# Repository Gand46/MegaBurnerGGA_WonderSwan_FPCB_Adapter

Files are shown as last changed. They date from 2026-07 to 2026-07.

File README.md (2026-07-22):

# WonderSwan SOP-44 to TSOP II-44 FPCB adapter

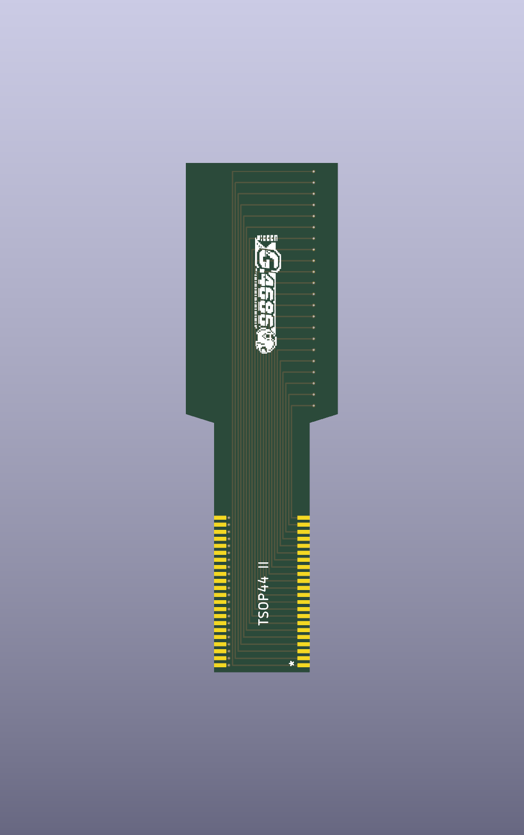
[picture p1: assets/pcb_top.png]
Top view of the final adapter


Final KiCad 9 project for a passive 44-pin flexible adapter intended for a WonderSwan cartridge.

## Validation status

- ERC: 0 violations.
- DRC: 0 violations.
- Unconnected items: 0.
- Schematic/PCB parity problems: 0.
- Structural validation: 32/32 checks passed.

## Design summary

| Parameter | Final value |
|---|---:|
| Flat dimensions | 17.30 x 58.00 mm |
| Hinge | 10.00 x 10.90 mm |
| Connectivity | 44 direct nets, `J1.N -> J2.N` |
| J1 | SOP-44, vertical, B.Cu, 90 degrees |
| J2 | TSOP II-44 edge pads, vertical, F.Cu, 180 degrees |
| J2 pad geometry | 1.40 x 0.45 mm, 0.80 mm pitch |
| Hinge routing | 22 tracks F.Cu + 22 tracks B.Cu, 0.15 mm |
| Vias | 44 total, none in hinge |
| Nominal FPCB thickness | 0.099 mm |
| Surface finish | ENIG |

J2 pin 1 points toward the outer end. Its flat copper contacts intentionally reach the PCB edge and are governed by the custom `.kicad_dru` rule.

## Repository structure

```text
hardware/kicad/          Editable KiCad project and local libraries
hardware/manufacturing/  Gerbers, drill files, IPC-2581 and fabrication notes
docs/                    Schematics, 1:1 drawings, validation report and provenance
assets/                  SVG and top/bottom 3D renders
validation/              ERC, DRC and structural reports
scripts/                 Reproducible validation and export tools
.github/workflows/       GitHub Actions validation
```

## Reproduce validation

Requires KiCad 9 and Python 3:

```bash
bash scripts/validate.sh
```

## Regenerate manufacturing outputs

```bash
bash scripts/export_fabrication.sh
```

To regenerate the illustrated validation report and the verified 1:1 mechanical template, install ReportLab and run:

```bash
python3 scripts/generate_documents.py
```

## Before fabrication

Print `docs/mechanical_template_verified_1to1.pdf` at 100 percent, with page scaling disabled, and measure both the 50 mm calibration bar and the documented 17.30 x 58.00 mm envelope. Confirm the physical SOP pin numbering, J2 alignment, cartridge clearance, FPCB stackup, ENIG edge-contact process, and static bend radius with the manufacturer.

This is a validated prototype design, not a substitute for manufacturer DFM approval or physical fit testing.

## License

Workingonit

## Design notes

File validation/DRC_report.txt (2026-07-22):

** Drc report for FPCB_SOP44_to_TSOPII44_REV_D2_EDGE_PADS_TOP_10MM.kicad_pcb **
** Created on 2026-07-22T00:00:06-0500 **
** Report includes: Errores, Avisos, Exclusiones **

** Found 0 DRC violations **

** Found 0 unconnected pads **

** Found 0 Footprint errors **

** End of Report **

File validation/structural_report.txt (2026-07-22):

FINAL STRUCTURAL VALIDATION
Project: FPCB_SOP44_to_TSOPII44_REV_D2_EDGE_PADS_TOP_10MM
Source: user-supplied proyecto_Final.zip

[OK] endpoint_references: References=['J1', 'J2']
[OK] forty_four_pads_per_endpoint: J1=44; J2=44
[OK] direct_pin_n_to_pin_n_mapping: 44 direct nets /PIN_01 through /PIN_44
[OK] j1_vertical_on_bottom: J1=(114.3, 114.3, 90.0 deg, B.Cu)
[OK] j2_vertical_rotated_180_on_top: J2=(114.3, 148.8, 180.0 deg, F.Cu)
[OK] j1_pad_layers: 44 pads B.Cu/B.Mask/B.Paste
[OK] j2_pad_layers: 44 edge pads F.Cu/F.Mask
[OK] all_endpoint_pads_smd_no_drill: 88 SMD pads, no pad drills
[OK] board_width_17_30mm: Width=17.300 mm
[OK] board_height_58_00mm: Height=58.000 mm
[OK] hinge_length_10_00mm: Y=129.60..139.60 mm
[OK] hinge_width_10_90mm: Sides=[108.85, 119.75]
[OK] via_count_44: Vias=44
[OK] no_vias_in_hinge: 0 vias in hinge
[OK] via_drill_0_20mm: Drill=0.20 mm
[OK] no_track_vertices_inside_hinge: Internal vertices=0
[OK] exactly_44_tracks_cross_hinge: Crossings=44
[OK] all_44_nets_cross_once: 44 unique nets
[OK] hinge_layers_22_plus_22: F.Cu=22; B.Cu=22
[OK] hinge_track_width_0_15mm: Width=0.15 mm
[OK] straight_vertical_hinge_tracks: 44 straight 10.00 mm segments
[OK] no_pads_in_hinge: 0 endpoint pads in hinge
[OK] j2_pad_size_1_40x0_45mm: Sizes=[(1.4, 0.45)]
[OK] j2_copper_reaches_both_edges: Copper=108.85..119.75 mm
[OK] j2_pitch_0_80mm: Pitch=0.8000 mm
[OK] j2_pin1_at_outer_end: Pin1=(119.050, 157.200) mm
[OK] logo_has_no_electrical_pads: Graphic logo only
[OK] custom_edge_rule_present: Intentional J2 edge contact rule
[OK] erc_clean: ERC violations=0
[OK] drc_clean: DRC violations=0
[OK] zero_unconnected_items: Unconnected=0
[OK] schematic_pcb_parity: Parity issues=0

RESULT: PASS (32/32)

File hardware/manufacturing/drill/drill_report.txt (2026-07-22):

Drill report for FPCB_SOP44_to_TSOPII44_REV_D2_EDGE_PADS_TOP_10MM.kicad_pcb
Created on 2026-07-21T23:55:25-0500

Copper Layer Stackup:
    =============================================================
    L1 :  F.Cu                      front
    L2 :  B.Cu                      back

Drill file 'FPCB_SOP44_to_TSOPII44_REV_D2_EDGE_PADS_TOP_10MM-PTH.drl' contains
    plated through holes:
    =============================================================
    T1  0.200mm  0.0079"  (44 holes)

    Total plated holes count 44

Drill file 'FPCB_SOP44_to_TSOPII44_REV_D2_EDGE_PADS_TOP_10MM-NPTH.drl' contains
    unplated through holes:
    =============================================================

    Total unplated holes count 0

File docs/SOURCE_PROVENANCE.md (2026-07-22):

# Source provenance

The sole design source for this final repository was the user-supplied archive:

`proyecto_Final.zip`

SHA-256:

`9b885df1952037dbf72eb71f1b5ff8135ade8380866d47dbfeffbfe19e24a85a`

The archive passed a complete ZIP integrity check.

## Cleanup performed

- Excluded `.DS_Store`, `__MACOSX`, `fp-info-cache`, and `.kicad_prl` from the repository.
- Did not reuse the uploaded `PCB_Final` fabrication exports because they predated the latest PCB save.
- Regenerated all manufacturing and documentation outputs from the final `.kicad_pcb` and `.kicad_sch` files.

## Metadata correction

The visible footprint reference fields had been changed from `J1` and `J2` to descriptive labels. KiCad therefore reported four schematic-parity problems and the custom J2 edge-contact rule did not match, causing 44 false edge-clearance errors.

The repository restores `J1` and `J2` as hidden internal references and preserves the descriptive labels as normal silkscreen text. This changes no pad, via, track, net, footprint placement, or board-outline coordinate.

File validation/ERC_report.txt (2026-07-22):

Informe de ERC (2026-07-22T00:00:05-0500, codificación UTF8)
Report includes: Errores, Avisos, Exclusiones

***** Hoja /

**Mensajes ERC: 0. Errores0, Avisos 0

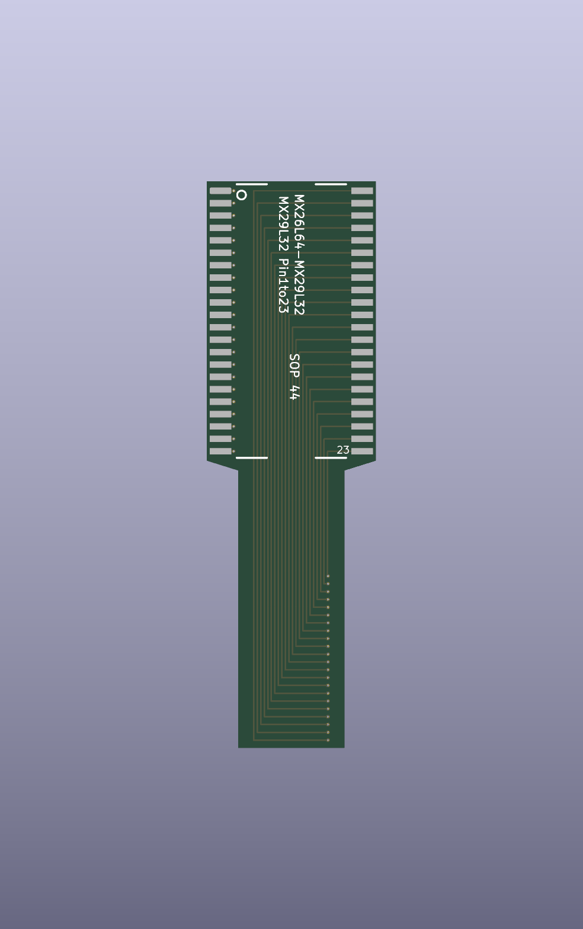
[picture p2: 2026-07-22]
assets/pcb_bottom.png

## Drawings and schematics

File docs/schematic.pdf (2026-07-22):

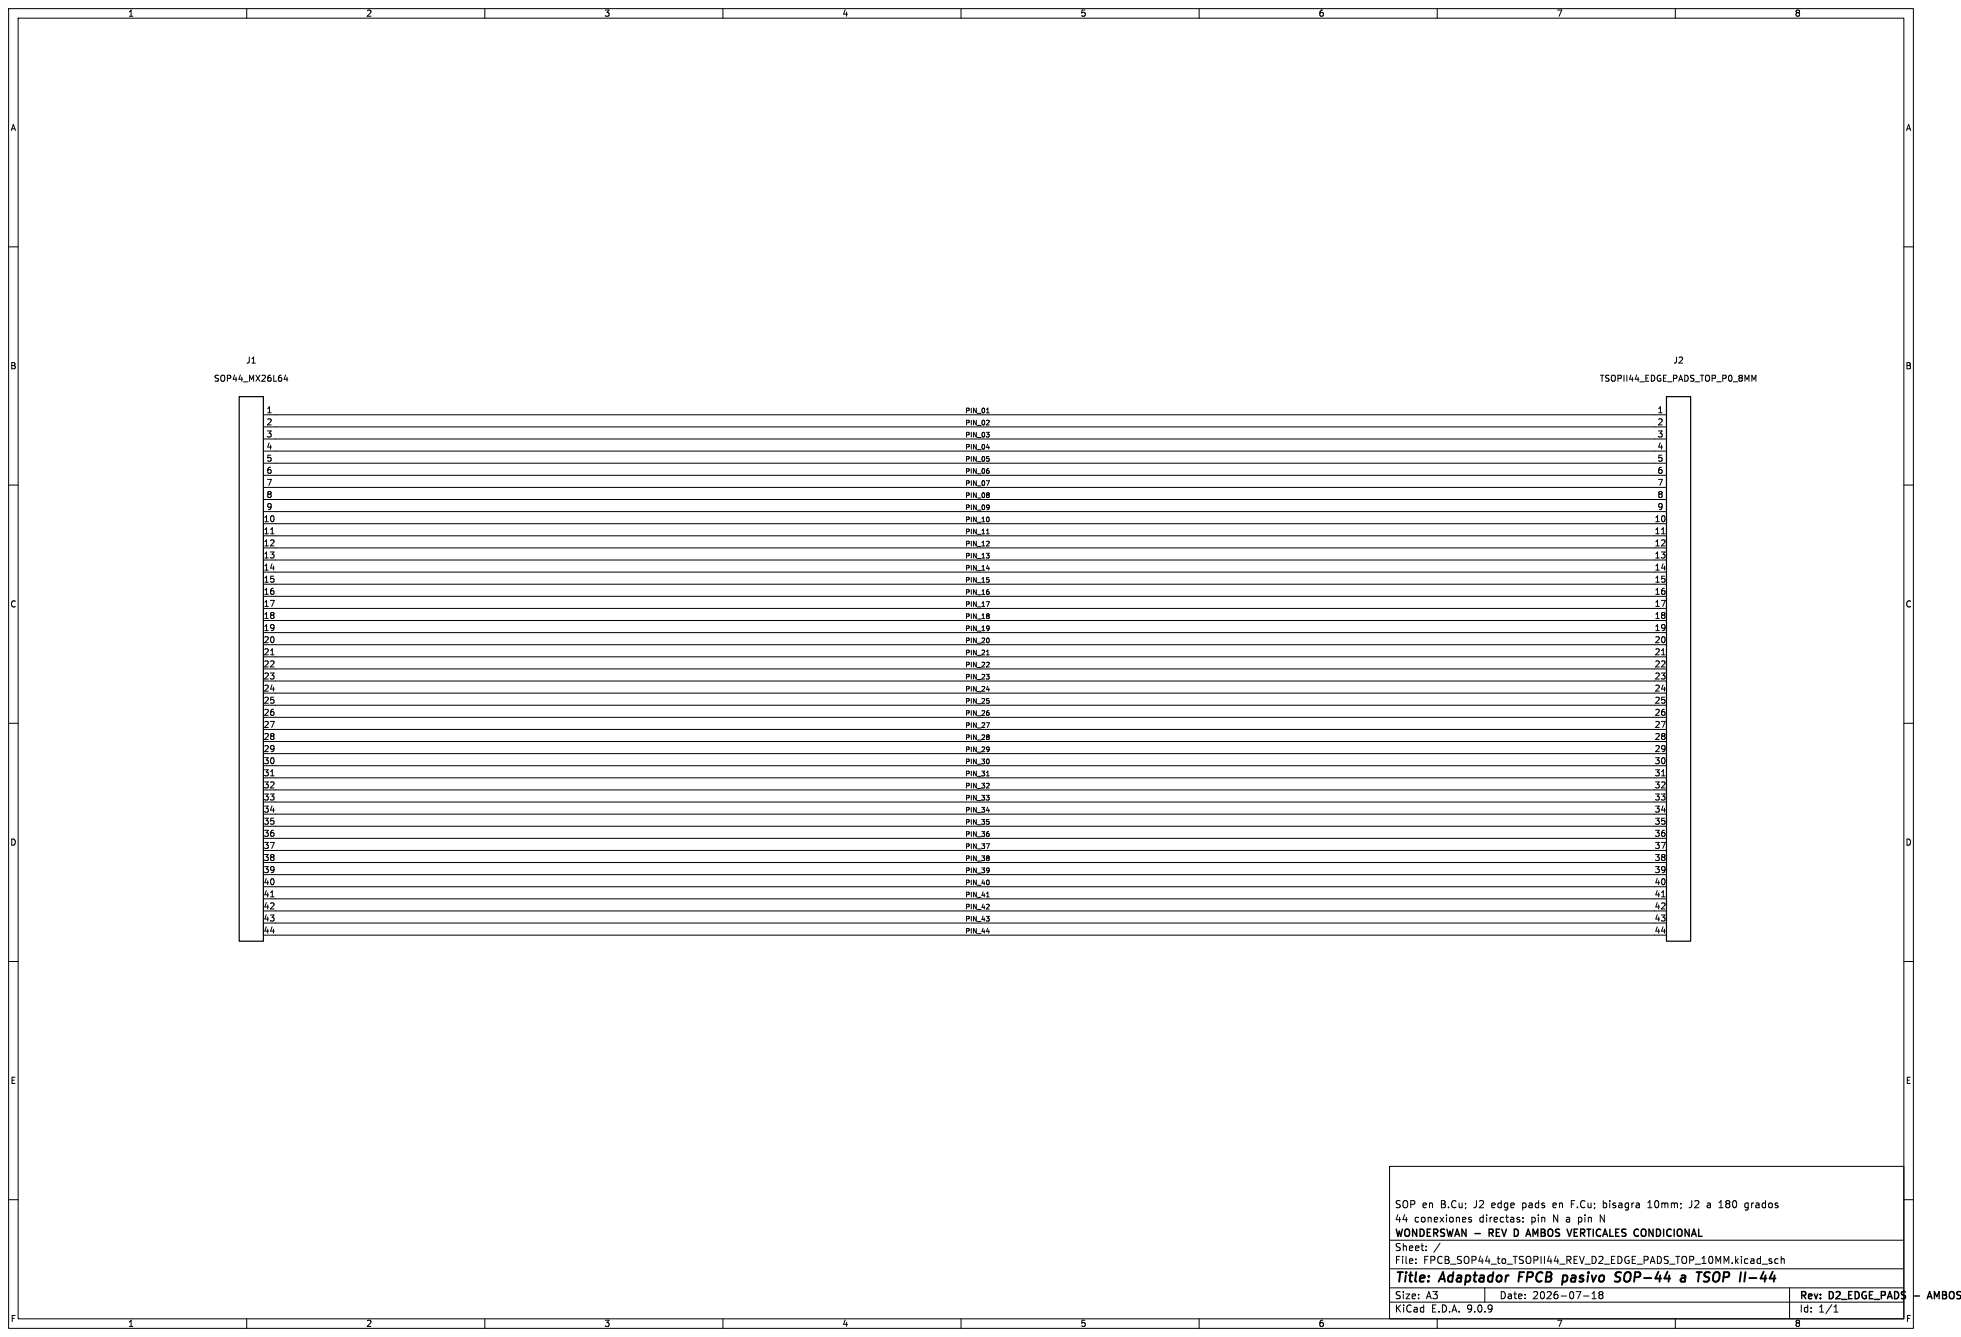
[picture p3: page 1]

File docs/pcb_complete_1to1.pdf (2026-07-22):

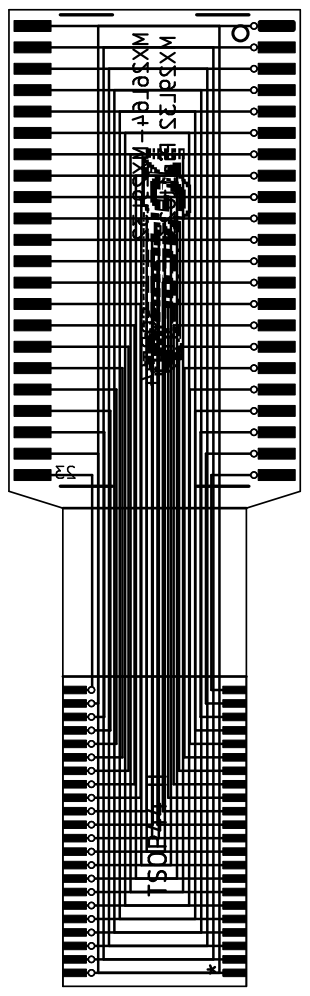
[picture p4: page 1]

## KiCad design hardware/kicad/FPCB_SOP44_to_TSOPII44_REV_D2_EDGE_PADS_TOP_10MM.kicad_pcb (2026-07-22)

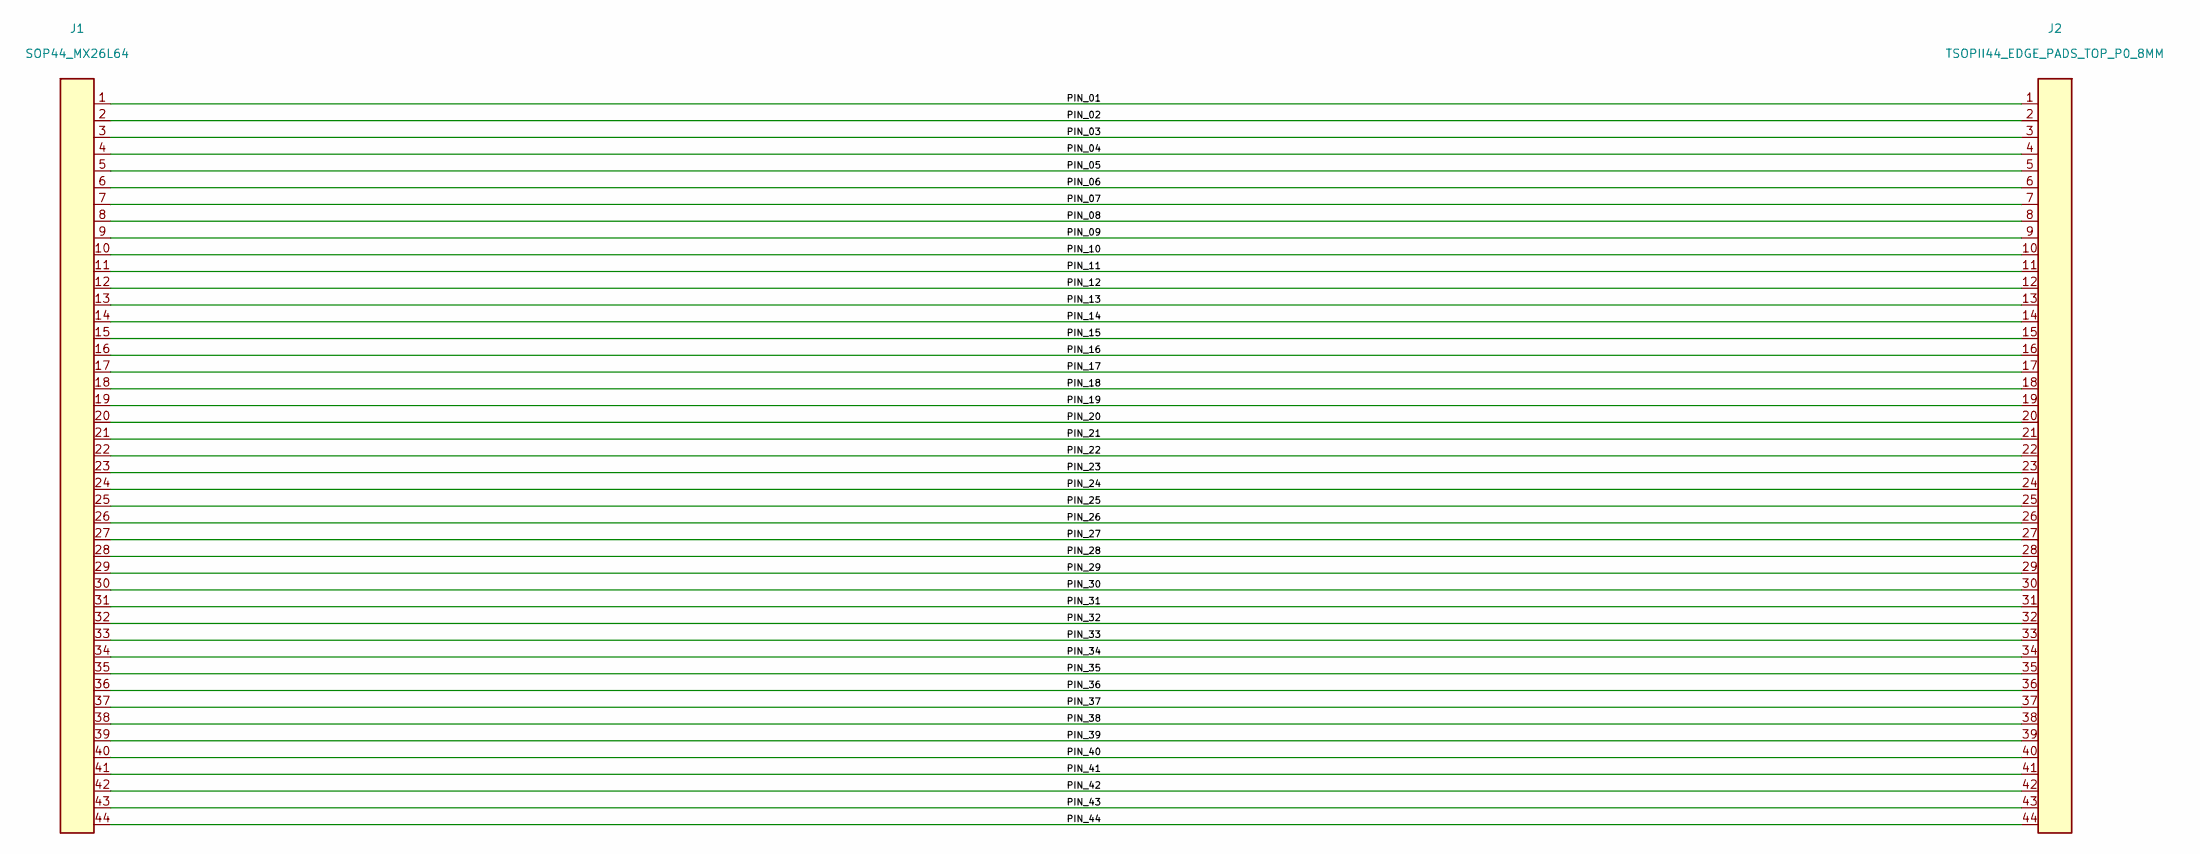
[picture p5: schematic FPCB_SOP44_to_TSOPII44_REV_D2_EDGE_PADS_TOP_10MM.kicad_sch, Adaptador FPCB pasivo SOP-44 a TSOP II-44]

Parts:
J1: SOP44_MX26L64; SOP44_MX26L64_BACK_VERTICAL
J2: TSOPII44_EDGE_PADS_TOP_P0_8MM

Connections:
/PIN_01: J1.1 (PIN_01), J2.1 (PIN_01)
/PIN_02: J1.2 (PIN_02), J2.2 (PIN_02)
/PIN_03: J1.3 (PIN_03), J2.3 (PIN_03)
/PIN_04: J1.4 (PIN_04), J2.4 (PIN_04)
/PIN_05: J1.5 (PIN_05), J2.5 (PIN_05)
/PIN_06: J1.6 (PIN_06), J2.6 (PIN_06)
/PIN_07: J1.7 (PIN_07), J2.7 (PIN_07)
/PIN_08: J1.8 (PIN_08), J2.8 (PIN_08)
/PIN_09: J1.9 (PIN_09), J2.9 (PIN_09)
/PIN_10: J1.10 (PIN_10), J2.10 (PIN_10)
/PIN_11: J1.11 (PIN_11), J2.11 (PIN_11)
/PIN_12: J1.12 (PIN_12), J2.12 (PIN_12)
/PIN_13: J1.13 (PIN_13), J2.13 (PIN_13)
/PIN_14: J1.14 (PIN_14), J2.14 (PIN_14)
/PIN_15: J1.15 (PIN_15), J2.15 (PIN_15)
/PIN_16: J1.16 (PIN_16), J2.16 (PIN_16)
/PIN_17: J1.17 (PIN_17), J2.17 (PIN_17)
/PIN_18: J1.18 (PIN_18), J2.18 (PIN_18)
/PIN_19: J1.19 (PIN_19), J2.19 (PIN_19)
/PIN_20: J1.20 (PIN_20), J2.20 (PIN_20)
/PIN_21: J1.21 (PIN_21), J2.21 (PIN_21)
/PIN_22: J1.22 (PIN_22), J2.22 (PIN_22)
/PIN_23: J1.23 (PIN_23), J2.23 (PIN_23)
/PIN_24: J1.24 (PIN_24), J2.24 (PIN_24)
/PIN_25: J1.25 (PIN_25), J2.25 (PIN_25)
/PIN_26: J1.26 (PIN_26), J2.26 (PIN_26)
/PIN_27: J1.27 (PIN_27), J2.27 (PIN_27)
/PIN_28: J1.28 (PIN_28), J2.28 (PIN_28)
/PIN_29: J1.29 (PIN_29), J2.29 (PIN_29)
/PIN_30: J1.30 (PIN_30), J2.30 (PIN_30)
/PIN_31: J1.31 (PIN_31), J2.31 (PIN_31)
/PIN_32: J1.32 (PIN_32), J2.32 (PIN_32)
/PIN_33: J1.33 (PIN_33), J2.33 (PIN_33)
/PIN_34: J1.34 (PIN_34), J2.34 (PIN_34)
/PIN_35: J1.35 (PIN_35), J2.35 (PIN_35)
/PIN_36: J1.36 (PIN_36), J2.36 (PIN_36)
/PIN_37: J1.37 (PIN_37), J2.37 (PIN_37)
/PIN_38: J1.38 (PIN_38), J2.38 (PIN_38)
/PIN_39: J1.39 (PIN_39), J2.39 (PIN_39)
/PIN_40: J1.40 (PIN_40), J2.40 (PIN_40)
/PIN_41: J1.41 (PIN_41), J2.41 (PIN_41)
/PIN_42: J1.42 (PIN_42), J2.42 (PIN_42)
/PIN_43: J1.43 (PIN_43), J2.43 (PIN_43)
/PIN_44: J1.44 (PIN_44), J2.44 (PIN_44)

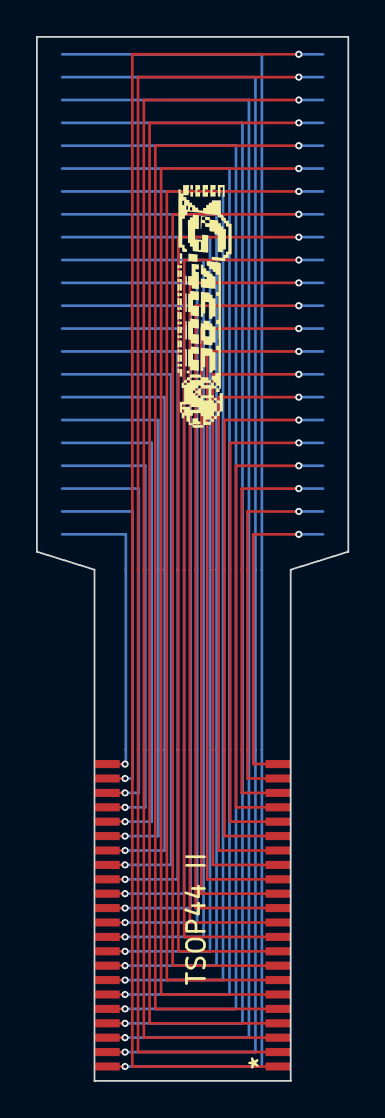
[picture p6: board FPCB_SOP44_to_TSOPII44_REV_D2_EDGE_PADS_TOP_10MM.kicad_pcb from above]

Board: 2 copper layers, 17.3 x 58.0 mm, 3 parts (1 on the bottom side), 44 nets.

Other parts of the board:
.: LOGO

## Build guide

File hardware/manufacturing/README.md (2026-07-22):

# Manufacturing package

These files are generated from the KiCad source with KiCad 9.0.9.

Key fabrication requirements:

- Two-layer FPCB.
- Nominal finished thickness: 0.099 mm or manufacturer-approved equivalent not exceeding 0.10 mm.
- Copper: 12 um nominal per layer.
- Finish: ENIG.
- Minimum track/space: 0.15/0.10 mm.
- Static 180-degree fold only; target bend radius at least 1.20 mm.
- Keep the 10.00 x 10.90 mm hinge free of stiffener, vias, pads, and added copper.
- J2 uses intentional flat copper contacts reaching Edge.Cuts. They are not castellated holes.
- Confirm edge-contact processing and outline tolerance with the FPCB manufacturer.

Regenerate this directory with:

```bash
bash scripts/export_fabrication.sh
```

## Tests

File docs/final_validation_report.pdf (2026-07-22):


WonderSwan FPCB adapter - final package - KiCad 9.0.9 | Pagina 1

# Informe final del adaptador FPCB

## SOP-44 a TSOP II-44 para cartucho WonderSwan

Resultado digital: ERC 0, DRC 0, sin conexiones abiertas, paridad completa y 32/32 comprobaciones estructurales aprobadas.

Parametro | Resultado final
Dimensiones desplegadas | 17,30 x 58,00 mm
Bisagra | 10,00 x 10,90 mm
Conectividad | 44 redes directas J1.N -> J2.N
J1 SOP-44 | Vertical, B.Cu, giro 90 grados
J2 TSOP II-44 | Vertical, F.Cu, giro 180 grados; pin 1 exterior
Pads J2 | 1,40 x 0,45 mm; paso 0,80 mm; cobre al borde
Ruteo en pliegue | 22 pistas F.Cu + 22 pistas B.Cu; ancho 0,15 mm
Vias | 44 totales; 0 dentro de la bisagra
Herramienta | KiCad 9.0.9

Vista superior regenerada desde el PCB final. J2 conserva sus contactos planos al borde y el pin 1 apunta hacia el extremo exterior.

WonderSwan FPCB adapter - final package - KiCad 9.0.9 | Pagina 2

## Validacion electrica y mecanica

El proyecto fue comprobado directamente con kicad-cli y con un analizador independiente de las S-expressions del PCB.

Comprobacion | Estado
ERC | 0 infracciones
DRC | 0 infracciones
Elementos sin conectar | 0
Paridad esquema/PCB | 0 problemas
Referencias internas | J1 y J2 coherentes
Pads por extremo | 44 + 44
Mapeo pin N a pin N | 44/44
Pistas que cruzan el pliegue | 44; una por red
Vias y pads dentro del pliegue | 0 / 0
Vertices de pista dentro del pliegue | 0
Validacion estructural | 32/32

### Zona flexible

La bisagra contiene 44 pistas verticales y rectas de 0,15 mm: 22 en F.Cu y 22 en B.Cu. No contiene vias, pads ni cambios de direccion. El ancho es 10,90 mm y la longitud libre es 10,00 mm.

### Interfaz J2

Los 44 pads J2 son SMD F.Cu/F.Mask, miden 1,40 x 0,45 mm, usan paso de 0,80 mm y alcanzan Edge.Cuts. No son castellated holes y no contienen perforaciones.

La regla personalizada de J2 debe conservarse. Su funcion es documentar que el contacto con Edge.Cuts es intencional; el fabricante debe aprobar el proceso de cobre/ENIG al borde.

WonderSwan FPCB adapter - final package - KiCad 9.0.9 | Pagina 3

## Fabricacion, trazabilidad y cierre

### Fuente maestra

Este repositorio se construyo exclusivamente desde el archivo proyecto_Final.zip aportado por el usuario. SHA-256: 9b885df1952037dbf72eb71f1b5ff8135ade8380866d47dbfeffbfe19e24a85a.

### Correccion no geometrica

Las etiquetas visibles habian sustituido los identificadores internos J1/J2. Se restauraron J1 y J2 para recuperar la paridad con el esquema y la regla de borde. Las etiquetas MX26L64-MX29L32 y TSOP44 II se conservaron como serigrafia independiente. No se cambio ninguna coordenada de pad, pista, via, huella o Edge.Cuts.

### Entregables regenerados

Grupo | Contenido
Fuentes | Proyecto KiCad, librerias locales y reglas personalizadas
Fabricacion | Gerbers, PTH/NPTH, mapas, informe de taladro e IPC-2581
Documentacion | Esquema, PCB 1:1, plantilla mecanica e informe final
Imagenes | SVG de capas y renderizados 3D superior/inferior
Automatizacion | Scripts reproducibles y workflow de GitHub Actions

### Condiciones antes de fabricar

1. Imprimir la plantilla verificada al 100 por ciento y medir la barra de 50,00 mm.
2. Superponer fisicamente el SOP y la PCB host para confirmar pin 1 y separaciones.
3. Confirmar pista/espacio 0,15/0,10 mm, cobre de 12 um, espesor <=0,10 mm y ENIG.
4. Mantener radio estatico >=1,20 mm y no usar como bisagra dinamica.
5. Obtener aprobacion DFM del fabricante para contactos de cobre al borde.

### Estado final

Proyecto aprobado digitalmente y organizado para control de versiones. La liberacion fisica continua condicionada a plantilla 1:1, prueba dentro del cartucho y DFM del fabricante FPCB.

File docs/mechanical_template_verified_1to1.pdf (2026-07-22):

# Plantilla mecanica final verificada

Imprimir al 100 % y desactivar cualquier ajuste de pagina

## PATRON DE MEDICION 1:1

17.30 mm

58.00 mm

## REFERENCIA AMPLIADA 2.5X

# No usar esta vista para medir. J1 SOP⁻⁴⁴ ⁻ BOTTOM J2 TSOP II-44 ⁻ TOP

PLIEGUE 10.00 mm

BARRA DE CONTROL: 50.00 mm

[ ] Barra mide 50.00 mm
[ ] Ancho maximo mide 17.30 mm
[ ] Largo desplegado mide 58.00 mm
[ ] Bisagra mide 10.00 x 10.90 mm
[ ] J2 pin 1 apunta al extremo exterior [ ] Caras J1 bottom / J2 top confirmadas
Final | 17.30 x 58.00 mm | pliegue 10.00 mm | KiCad 9.0.9 | Escala primaria 1:1

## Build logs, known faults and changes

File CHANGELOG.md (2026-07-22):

# Changelog

## Final repository package - 2026-07-21

- Imported the user-supplied `proyecto_Final.zip` as the sole design source.
- Preserved the edited PCB geometry, routing, logo, component labels, and fabrication intent.
- Restored internal PCB references `J1` and `J2` to match the schematic.
- Preserved `MX26L64-MX29L32` and `TSOP44 II` as independent silkscreen text.
- Regenerated ERC, DRC, Gerbers, drill files, IPC-2581, PDFs, SVG, and 3D renders with KiCad 9.0.9.
- Added reproducible structural validation and GitHub Actions configuration.
